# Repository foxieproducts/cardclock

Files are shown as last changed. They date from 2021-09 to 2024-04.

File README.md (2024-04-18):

# Check out the new [Foxie CardClock 2.0](https://github.com/foxieproducts/cardclock2)!

## Foxie CardClock 1.0

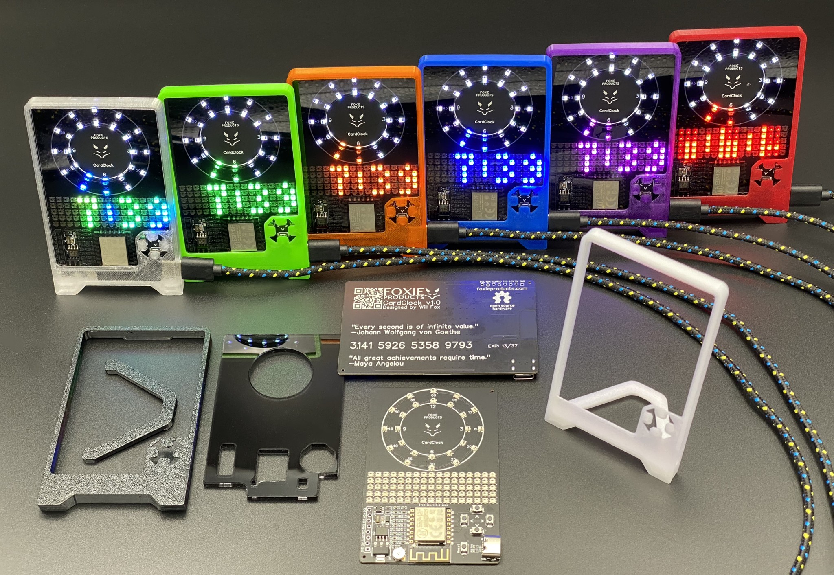
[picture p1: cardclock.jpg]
Foxie CardClock


### A smart, colorful, credit card sized clock

This is the Foxie CardClock, a certified Open Hardware ([OSHW US002055](https://certification.oshwa.org/us002055.html)), ESP8266-powered, WiFi-enabled, RTC-havin', super-capacitor havin', analog+digital, LED-laden, clock. The firmware is also able to self-update from the web, so improvements to this firmware can make their way to everyone's clocks.

There are 2 rings of 12 LEDs at the top of the PCB, which are used to display Hours, Minutes and Seconds. The Minutes and Seconds display with a 5 minute/second resolution.

Enter the 17x5 LED matrix, including a library that has functions for drawing characters, scrolling, and more. All A-Z, 0-9 and most symbols are supported (see [characters.hpp](firmware/src/characters.hpp)). Easy-to-read source code. 

There are also 4 buttons for up/down/left/right navigation, and finally a reset button for the ESP8266 programming. Hold the **down** button, then press reset to enter UART **down**load mode. Too cool for serial programming? The CardClock firmware also supports ArduinoOTA and most firmware development can be done wirelessly, as long as you don't make the firmware unbootable... if you do, grab your USB-to-serial adapter and reprogram it easily. 

There is a light sensor using the ESP8266's single analog input, providing for a smooth experience in brighter and darker environments. Minimum and maximum brightness are also easily adjustable directly on the clock using the menu system.

The CardClock syncs NTP time once a minute from the WiFi connection. It also keeps track of time using the onboard RTC. Unplug your clock? No problem, the time isn't lost because the built-in super-capacitor will keep the RTC powered for over 2 days. The moment you plug it back in, the time is still there, and if on WiFi, will be NTP sync'd moments later. It's the little things, right?

You can even 3d-print your own [case](case/) easily with nearly any 3d printer or easily modify it, with the included .step file. 

The [PCB](pcb/) was designed with EasyEDA.

## Easy to hack

The CardClock is powered by an Ai-Thinker ESP-12F, one of several modules based on the Espressif ESP8266. The ESP-12F is the same chip as in the NodeMCU and Wemos D1 products... could you get a python version of the CardClock firmware running? Might be a fun project!

The source code is written in object-oriented C++, built using PlatformIO inside VS Code. It has ArduinoOTA support (DEVL mode must be enabled in the clock's menu), along with a safe mode (hold the **left** button on boot) just in case you manage to brick the firmware somewhere after the initialization. Although, I highly recommend having a USB to Serial cable (such as a CP2102 MICRO USB to UART TTL Module) around, just in case.

The firmware uses several open-source libraries, including [ESPAsyncWiFiManager](https://github.com/alanswx/ESPAsyncWiFiManager]), [Rtc_Pcf8563](https://github.com/elpaso/Rtc_Pcf8563), [Adafruit's NeoPixel library](https://github.com/adafruit/Adafruit_NeoPixel) and all the amazing work from the [ESP8266 Arduino core](https://github.com/esp8266/Arduino) team.

# [Get your own](https://www.foxieproducts.com/)

Order your own at [foxieproducts.com/products/cardclock](https://www.foxieproducts.com/products/cardclock) or at the [Foxie Products store on Tindie](https://www.tindie.com/products/foxieproducts/foxie-cardclock/).

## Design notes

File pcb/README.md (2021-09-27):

# Printed Circuit Board

The CardClock PCB was designed with [EasyEDA](https://easyeda.com). The top layer has a copper pour for the GND net, while the bottom has two: a 3.3v area under the primary component area and a 5v area everywhere else. 
There is also a keep-out area underneath the ESP-12F antenna area.

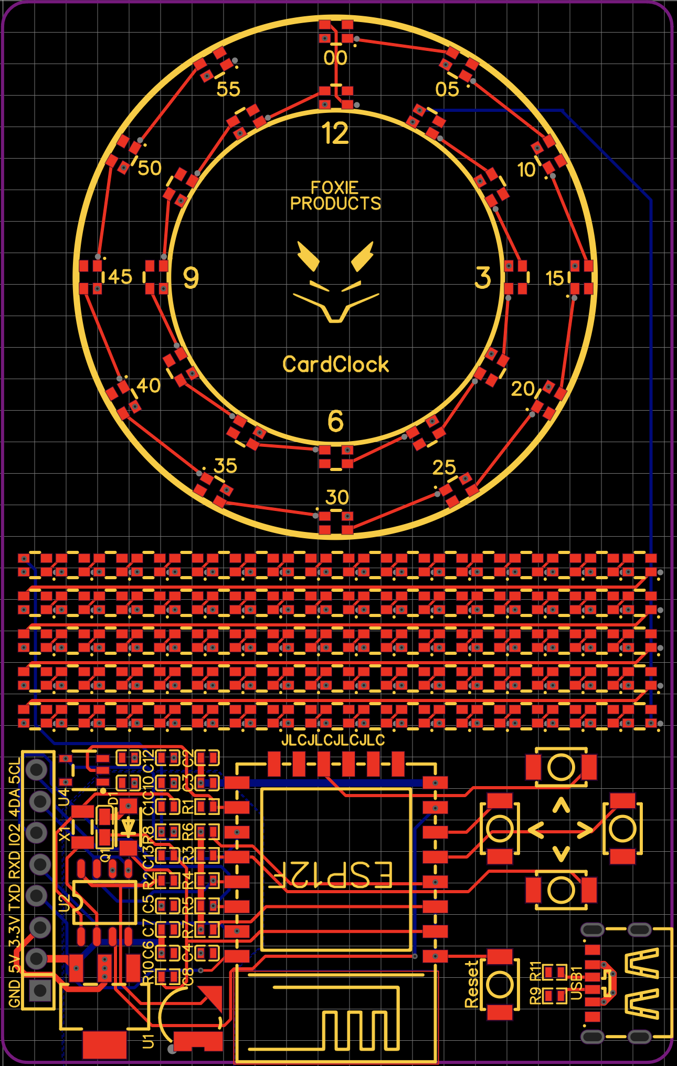
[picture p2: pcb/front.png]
Front
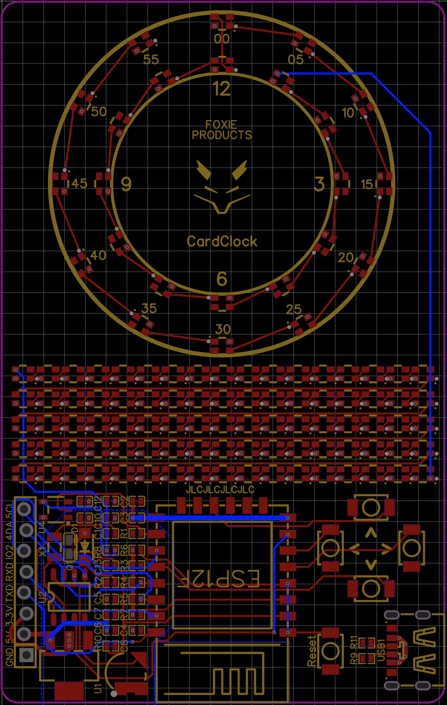
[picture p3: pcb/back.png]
Back
 

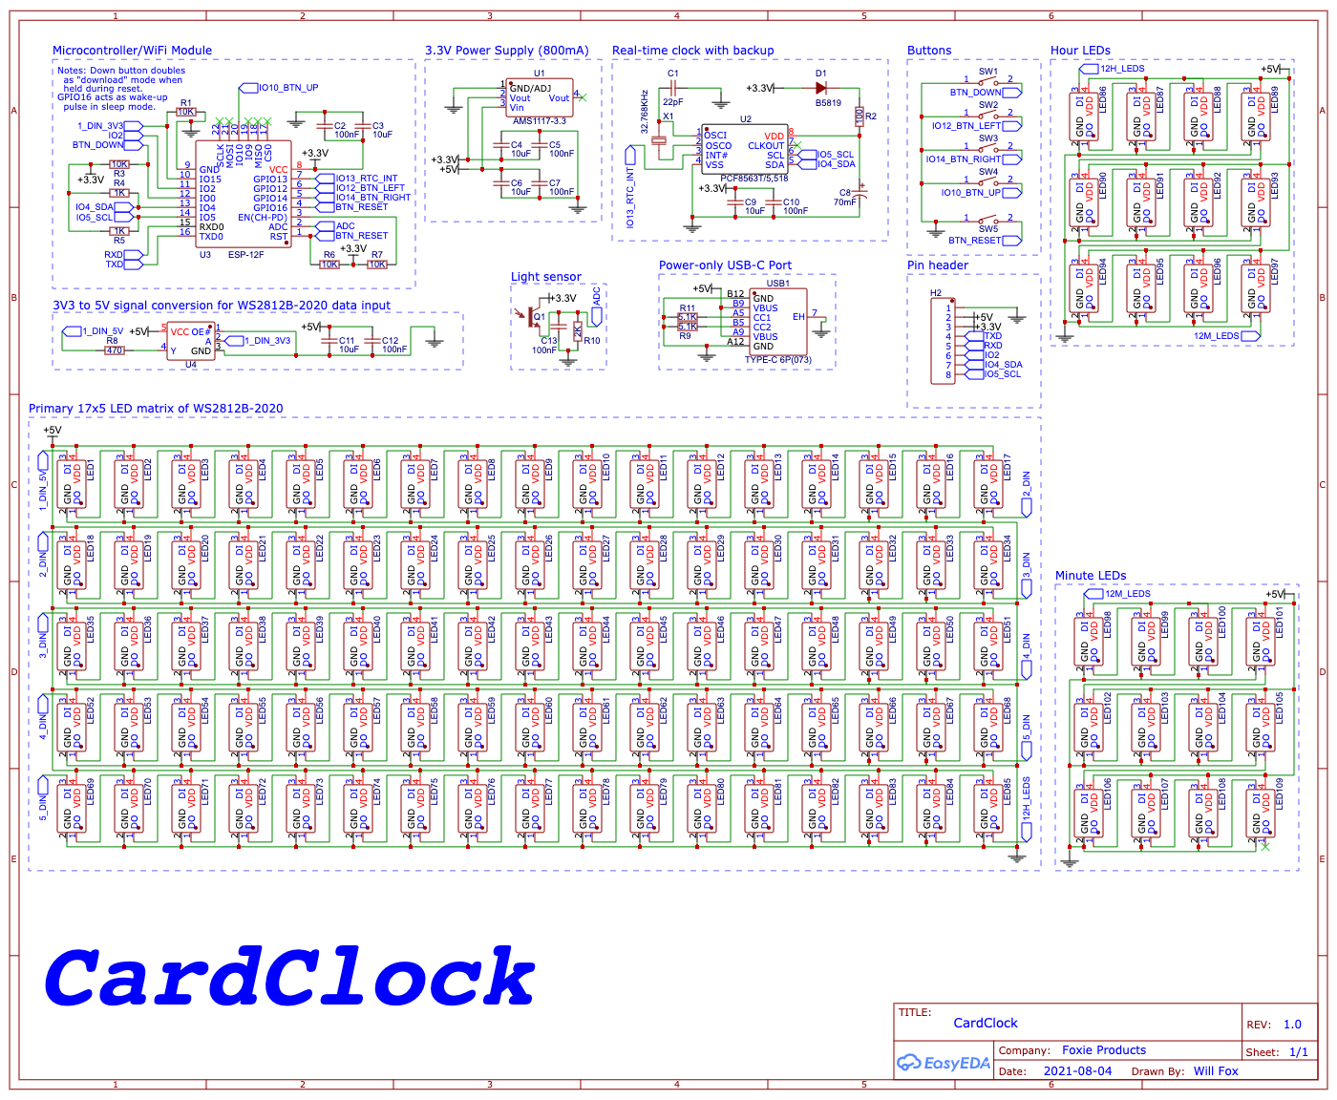
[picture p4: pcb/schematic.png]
Schematic


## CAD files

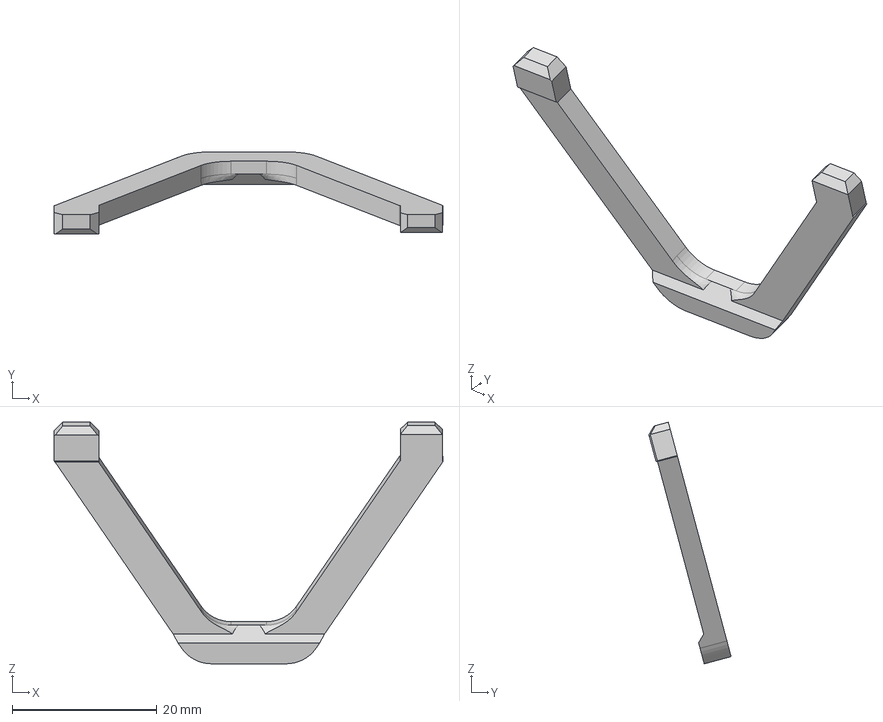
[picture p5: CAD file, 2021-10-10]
case/stand.step
53.7 x 11.4 x 33.4 mm

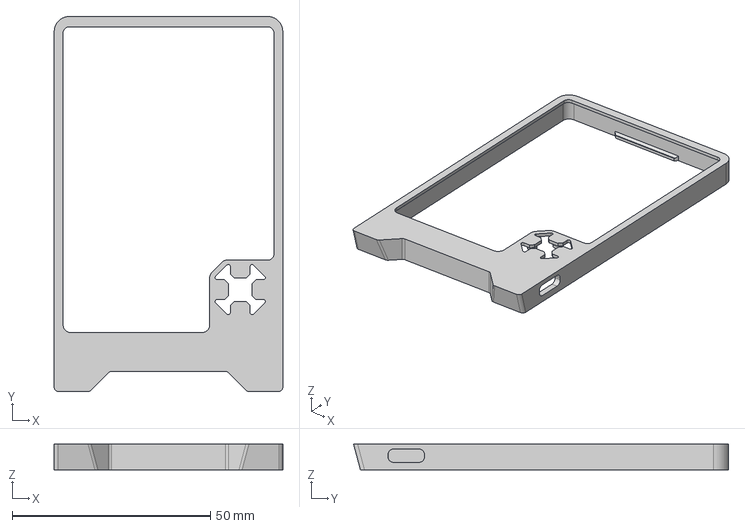
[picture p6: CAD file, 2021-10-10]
case/case.step
57.6 x 94.5 x 6.50 mm

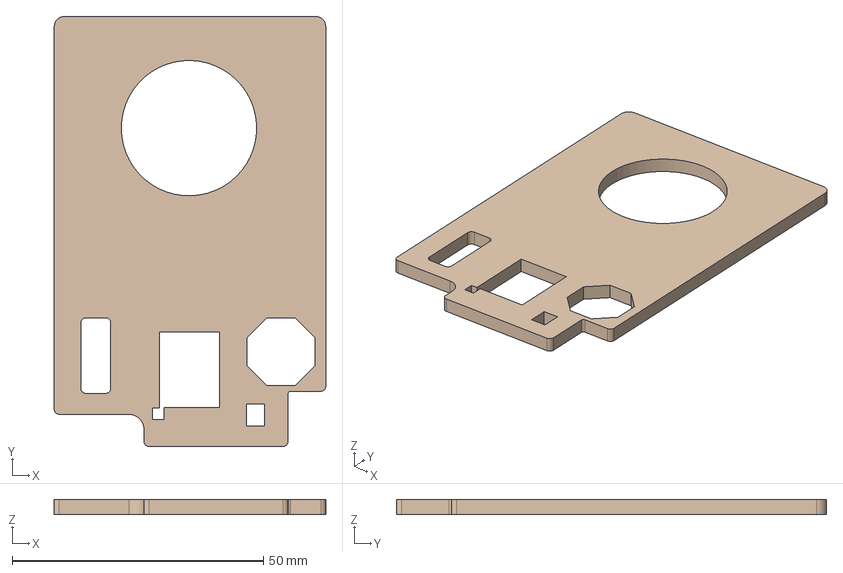
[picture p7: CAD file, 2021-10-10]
case/acrylic.step
54.0 x 85.5 x 3.00 mm

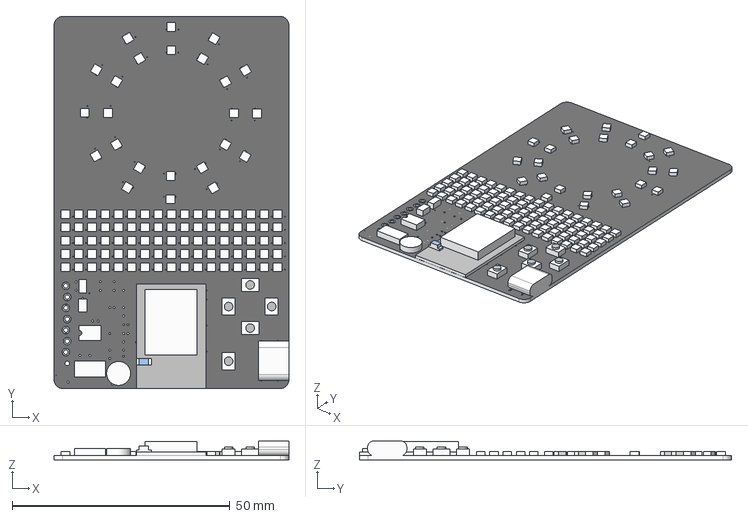
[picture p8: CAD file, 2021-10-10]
case/pcb.step
54.0 x 85.5 x 4.35 mm

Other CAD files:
case/case.3mf
case/stand.3mf

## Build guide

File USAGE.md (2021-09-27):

## CardClock Usage
---
[Set time]   <->   [Clock]   <->   [Configuration]

The CardClock starts up on the Clock screen.

Press **left** button to move from Clock to **set time**.
Press **right** button to move from Clock to **configure settings**.

Note: It is normal for the area by the Open Hardware gear on the back of the clock to be slightly warm.

## Changing the look on the Clock screen
---
Press the **up** button repeatedly to change the color at any time. A color wheel palette will be shown for a few moments. **Hold** down the **up** button to change colors more quickly.

Press the **down** button to change the **display mode**. There are several, and the list will loop back to the beginning once the end is reached.
Normal, Shimmer, Rainbow, Marquee, Marquee Rainbow, Binary, and Binary Shimmer 

## Setting the time
---
Press **left** button to move from Clock to **set time**.

Press left/right to switch between setting the hour, minute, or second.
Press up/down to increase or decrease the value. Hold the button down to move toward a value more quickly.
To exit, either wait 5 seconds or move to the seconds value and press the right button to move back to the Clock screen.

## Configuring settings
---
Press **right** button to move from Clock to **configure settings**.

Press the up/down buttons to move through the list of settings. The ring LEDs will display the position in the list.
Press the right button to select a setting, then press the up/down buttons to change the value.
To exit, either wait 5 seconds or press the left button to move back to the Clock screen.

MINB - MINimum Brightness - A setting below 8 will lose quite a bit of color variation

MAXB - MAXimum Brightness 

CLKB - CLocK Background - If enabled, the analog clock LEDs will be on

WLED - Wireless status LED - if enabled, an LED between the : separator will give status about whether the CardClock WiFi is connecting (heartbeat blink) or connected (solid)

24HR - 24 HouR - if enabled, hours are shown from 00:00-23:00 instead of 12:00-12:00

UTC - Universal Time Code offset - changes the time received from the Internet (UTC 0) to your local time zone. PDT = -7, MDT = -6, CDT = -5, EDT = -4, etc. 

WIFI - Configuring WiFi sets up SSID "Foxie_WiFiSetup" - connect from your phone, then you can set the CardClock to connect to your home WiFi for automatic NTP time synchronization.

INFO - Shows several bits of INFOrmation about the running state of the clock, including IP address (on WiFi)

VER - Shows the current VERsion of firmware

DEVL - DEVeLoper mode, enables AndroidOTA firmware updates over WiFi

UPDT - UPDaTe checks the current version of firmware from foxieproducts.com and prompts to confirm.

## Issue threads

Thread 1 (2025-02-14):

Compile errors

dunk8888, 2025-02-14:
Hi what boards version did you use for the ESP8266 also what was the rtc library version. Also Ide version ive tryed loads of different combos they  all gave different errors

foxieproducts, 2025-02-14:
Hi, I'm sorry you're having trouble building the firmware. Can you please attach the output errors you've seen?

dunk8888, 2025-02-16:
Hi its compiled now but getting bootloop error

rf cal sector: 1020
freq trace enable 0
rf[112] : 0a

foxieproducts, 2025-02-16:
I've never encountered that issue. Can you give some more details as to how you're loading the firmware and what you had to change to get it to compile?

dunk8888, 2025-02-18:
Well to start with i was trying to use Arduino ide as ive no experience with PlatformIO so tryed sorting the firmware out to run in Arduino ide, i failed with that and thought ive got to vive PlatformIO a go, turns out its quite easy to get grips with, so i grabes this firmware again nice and fresh and used PlatformIO, first i tryed uploading through serial but produced the rf error above, having googled about i read its ota firmware so i got to using the ota feature and flashed ok but still rf issue, i am using an R1 mini at the minute ile get an esp12f and try that, i did change the board to d1 mini in the Platformio. ini ive changed one button pin wich may of conflicted with things, so thats where ime at, ime gona order the proper esp its probably the d1 mini.

foxieproducts, 2025-02-18:
I appreciate the feedback and I'm sorry you're having trouble getting it going on your hardware.

I don't have any more original CardClocks (this repo, where the CC is vertical), but I did a new CardClock 2.0 (https://github.com/foxieproducts/cardclock2) last year, which you can also see at http://foxieclock.com. I still have a few available of my 2.0 designs.

dunk8888, 2025-02-26:
Hi no worries, i have seen the CC2 and FC2 shipping is same price as clock
to my home, but its ok ive made gerbers of the CC1 an its been fabed, ile
enjoy soldering all them leds on 😁 its debugging code the bugs me Good way
of learning.
So ile build the clock then see if i can get the firmware going on it,
whats the best way to upload, ota or esptools, i think my problem is the d1
mini i used ive seen loads online with same issue same board, its just bad
parts or config of the cheap boards

On Tue, 18 Feb 2025, 8:48 pm foxieproducts, ***@***.***>
wrote:

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

dunk8888, 2025-03-01:
Do you have a binery ide could flash to rule out code isue, ime having same results with an esp12f

foxieproducts, 2025-03-01:
I don't have a binary to provide, unfortunately. Good luck with your project. I'm going to close this ticket and I wish you luck.

Closed 2025-03-01.

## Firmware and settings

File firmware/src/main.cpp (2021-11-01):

#include <Arduino.h>
#include <ESP8266WiFi.h>
#include <LittleFS.h>
#include <user_interface.h>  // for ESP-specific API calls
#include <memory>            // for std::shared_ptr

// you might be asking yourself -- why is all the code in header files?
// answer: in a relatively small project like this, the separation of .hpp/.cpp
// files adds an unnecessarily cumbersome layer to rapid iteration

#include "clock.hpp"
#include "config_menu.hpp"
#include "display.hpp"
#include "foxie_ntp.hpp"
#include "foxie_wifi.hpp"
#include "option.hpp"
#include "settings.hpp"
#include "time_menu.hpp"
#include "web_update.hpp"

void CheckButtonsOnBoot(Settings& settings, Display& display, FoxieWiFi& wifi);

void setup() {
    using namespace std;
    auto settings = make_shared<Settings>();
    auto display = make_shared<Display>(*settings);
    auto wifi = make_shared<FoxieWiFi>(*settings, *display);
    auto updater = make_shared<WebUpdate>(*settings, *display);

    CheckButtonsOnBoot(*settings, *display, *wifi);

    auto rtc = make_shared<Rtc>(*settings);
    auto ntp = make_shared<FoxieNTP>(*settings, *rtc);
    auto menuMgr = make_shared<MenuManager>(*display, *settings);

    menuMgr->Add(make_shared<TimeMenu>(*display, *rtc, *settings));  // menu 0
    menuMgr->Add(make_shared<Clock>(*display, *rtc, *settings));     // menu 1

    // all config menu options are below
    auto configMenu = make_shared<ConfigMenu>(*display, *settings);  // menu 2
    configMenu->AddRangeSetting(F("MINB"), MIN_BRIGHTNESS, MAX_BRIGHTNESS);
    configMenu->AddRangeSetting(F("MAXB"), MIN_BRIGHTNESS, MAX_BRIGHTNESS);
    configMenu->AddTextSetting(F("CLKB"), {F("OFF"), F("ON")});
    configMenu->AddTextSetting(F("WLED"), {F("OFF"), F("ON")});
    configMenu->AddTextSetting(F("24HR"), {"OFF", "ON"});
    configMenu->AddRangeSetting(F("UTC"), -12, 12,
                                [&]() { ntp->UpdateRTCTime(); });
    configMenu->AddTextSetting(F("WIFI"), {"OFF", "ON", "CFG"});
    configMenu->AddRunFuncSetting(F("INFO"), [&]() {
        String info;
        info += F("IP:");
        info +=
            WiFi.isConnected() ? WiFi.localIP().toString() : F("NOT CONNECTED");
        info += F(" FH:") + String(ESP.getFreeHeap());
        info += F(" FCS:") + String(ESP.getFreeContStack());
        info += F(" UPT:") + String(millis() / 1000 / 60);

        display->DrawTextScrolling(info, GREEN);
    });
    configMenu->AddRunFuncSetting(F("VER"), [&]() {
        display->DrawTextScrolling(F("FC/OS v") + String(FW_VERSION) +
                                       F(" and may the schwartz be with you!"),
                                   PURPLE);
    });
    configMenu->AddTextSetting(F("DEVL"), {F("OFF"), F("ON")});
    configMenu->AddRunFuncSetting(F("UPDT"), [&]() { updater->Download(); });
    menuMgr->Add(configMenu);

    menuMgr->SetDefaultAndActivateMenu(1);  // clock menu

    // use a while loop instead of loop() ... I just hate globals, OK?
    while (true) {
        rtc->Update();
        ntp->Update();
        menuMgr->Update();
        wifi->Update();
        display->Update();

        yield();  // allow the ESP's system/WiFi code a chance to run
    }
}

void CheckButtonsOnBoot(Settings& settings, Display& display, FoxieWiFi& wifi) {
    pinMode(PIN_BTN_UP, INPUT_PULLUP);
    pinMode(PIN_BTN_DOWN, INPUT);
    pinMode(PIN_BTN_LEFT, INPUT_PULLUP);
    pinMode(PIN_BTN_RIGHT, INPUT_PULLUP);

    // if left button is held on boot, go into safe mode. this still allows
    // ArduinoOTA to function and the firmware can be updated using espota
    // just in case you accidentally put the board into a reboot loop that
    // doesn't involve any of the code this "safe" mode depends on...
    if (Button::AreAnyButtonsPressed() == PIN_BTN_LEFT) {
        display.DrawTextCentered(F("SAFE"), ORANGE);
        settings[F("DEVL")] == F("ON");
        while (true) {
            wifi.Update();
            display.Update();

            yield();  // allow the ESP's system/WiFi code a chance to run
        }
    }

    // if UP button is held on boot, clear settings.
    if (Button::AreAnyButtonsPressed() == PIN_BTN_UP) {
        display.SetBrightness(20);
        display.DrawText(0, F("CLR?"), ORANGE);
        display.DrawChar(14, CHAR_RIGHT_ARROW, GREEN);
        display.Show();

        if (Button::WaitForButtonPress() == PIN_BTN_RIGHT) {
            display.DrawTextScrolling(F("SETTINGS CLEARED"), PURPLE);
            settings.clear();
            settings.Save();
            ESP.eraseConfig();
            Rtc_Pcf8563 rtc;
            rtc.zeroClock();
            Button::WaitForNoButtons();
            ESP.restart();
        }
    }
}

void loop() {}

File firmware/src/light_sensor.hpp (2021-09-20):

#pragma once
#include <Arduino.h>         // for map()
#include <stdint.h>          // for uint16_t and others
#include <user_interface.h>  // for ESP-specific API calls

#include "elapsed_time.hpp"

/**
 * This class solves two problems:
 * 1. It uses the ESP API to read multiple samples from the ADC.
 *    The main reason this is used instead of analogRead() is because
 *    analogRead() is unstable on the ESP8266 and crashes often (???)
 * 2. It provides averaging so that light changes happen gradually,
 *    which helps eliminate flicker
 * */
class LightSensor {
  public:
    enum {
        ADC_SAMPLES = 8,
        ADC_CLOCK_DIVIDER = 8,
        MIN_SENSOR_VAL = 10,  // affected by side lighting from the display LEDs
                              // below this level
        MAX_SENSOR_VAL = 100,
        JITTER = 3,

        HISTORY_SIZE = 80,
    };

  private:
    uint16_t* m_samples{nullptr};
    uint16_t* m_history{nullptr};
    size_t m_historyPos{0};

    ElapsedTime m_timeSinceBrightnessSet;
    float m_curBrightness{0.0f};

  public:
    LightSensor() {
        m_samples = (uint16_t*)zalloc(ADC_SAMPLES * sizeof(uint16_t));
        m_history = (uint16_t*)zalloc(HISTORY_SIZE * sizeof(uint16_t));

        for (size_t i = 0; i < HISTORY_SIZE; ++i) {
            m_history[i] = GetCurrentADCValue();
        }
        m_curBrightness = GetHistoryMean();
    }

    size_t Get() {
        m_history[m_historyPos] = GetCurrentADCValue();
        if (m_historyPos++ == HISTORY_SIZE) {
            m_historyPos = 0;
        }

        uint16_t mean = GetHistoryMean();
        if (m_timeSinceBrightnessSet.Ms() > 40) {
            if (mean < m_curBrightness - JITTER ||
                mean > m_curBrightness + JITTER) {
                // move quickly toward current brightness
                m_curBrightness = (mean + m_curBrightness) / 2;
            } else {
                // move slowly toward current brightness
                if (m_curBrightness >= MAX_SENSOR_VAL - JITTER) {
                    // increase the mean slightly so we can get to
                    // MAX_SENSOR_VAL
                    mean++;
                }
                const float value = (99.0f * m_curBrightness) + mean;
                m_curBrightness = value / 100.0f;
            }
            m_timeSinceBrightnessSet.Reset();
        }

        return m_curBrightness;
    }

  private:
    size_t GetHistoryMean() {
        size_t mean = 0;
        for (size_t i = 0; i < HISTORY_SIZE; i++) {
            mean += m_history[i];
        }

        return mean / HISTORY_SIZE;
    }

    // get a smoothed, bounded value from the sensor
    size_t GetCurrentADCValue() {
        system_soft_wdt_stop();
        ets_intr_lock();
        noInterrupts();

        system_adc_read_fast(m_samples, ADC_SAMPLES, ADC_CLOCK_DIVIDER);

        interrupts();
        ets_intr_unlock();
        system_soft_wdt_restart();

        size_t mean = 0;
        for (size_t i = 0; i < ADC_SAMPLES; i++) {
            mean += m_samples[i];
        }
        return constrain((mean / ADC_SAMPLES), MIN_SENSOR_VAL, MAX_SENSOR_VAL);
    }
};

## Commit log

2021-09-08 Improved light sensor class further, still working on it
2021-09-08 Now displays current second on the minute LEDs
2021-09-12 Default button repeat to true
2021-09-13 Fix hw_test minor breaks due to recent changes in Display and Button
    [hw_test.cpp]
2021-09-13 Relocate Pins_e to button.hpp
2021-09-13 More light sensor tweaks. Won't be the last.
    [light_sensor.hpp]
2021-09-15 Build fixes for hw_test and main
    [main.cpp]
2021-09-15 ArduinoOTA updates now working
2021-09-15 Another improvement to hopefully fix the clock interrupts correctly on boot
2021-09-15 Move WiFi status LED display to ClockMenu
2021-09-15 Change WiFi status LED to white
2021-09-16 Pressing a button while scrolling a message increases speed
2021-09-16 Make button repeats faster
2021-09-16 Switch to using MINB and MAXB settings for brightness
2021-09-16 Add option to disable wireless status LED
2021-09-17 Switch display characters to be in code instead of RAM, saves about 4K of RAM which is needed for the web update code.
2021-09-17 Show % during ArduinoOTA updates
2021-09-17 Switching to inline flash strings to save heap
2021-09-17 Interrupt guard call to updating pixels, still experiencing a rare random reboot
    [display.hpp]
2021-09-17 Switch to std::make_shared
2021-09-17 More light sensor tweaks
2021-09-18 Reworked light sensor code, behaves far better
    [light_sensor.hpp]
2021-09-18 Remove static Buttons::Update method
2021-09-18 OTA/Web Update improvements, back button now cancels update
2021-09-18 RTC Millis() backup method should include 1000
2021-09-18 Switch to uint32_t for colors
2021-09-19 Fix DrawTextScrolling so it doesn't ignore brightness
    [button.hpp, display.hpp]
2021-09-19 Fix bug with message color coming out of rainbow mode
    [clock.hpp]
2021-09-19 Speed up vertical scrolling and shorten button debounce time
    [button.hpp, display.hpp]
2021-09-20 Renaming, cleanup and bug fixes, oh myyy
    [button.hpp, clock.hpp, display.hpp]
2021-09-20 Restore the accidentally removed code that disables blue LED
2021-09-20 Improved handling of ring LEDs at low display brightness levels
2021-09-20 Ensure that RTC::Millis() does not return more than 1000
2021-09-20 Fix below-default brightness adjustment
    [clock.hpp]
2021-09-20 Pressing left/right buttons should also reset the timeout
2021-09-20 Improve the button-related code outside the Menus a little bit
2021-09-21 Fix bug with wifi status LED blinking when settings are cleared and WiFi isn't enabled
    [clock.hpp]
2021-09-21 Adding case resources
    [case.3mf, case.step, stand.3mf]
2021-09-22 Adding EasyEDA pcb and schematic
2021-09-25 RangeListOption can change the setting on each button press. This is useful for the MINB and MAXB settings, because they're constantly being used as the display updates. So now, turning the brightnes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
2021-09-26 Reset clock to zero when settings are cleared (holding UP button on boot)
    [main.cpp]
2021-09-26 Adding images of schematic, back and front of PCB
2021-09-26 Re-export schematic png
2021-10-10 Include .step files for all parts
    [acrylic.step, case.step, pcb.step]
2021-10-10 Separate case and stand step files
    [case.step, stand.step]
2021-12-16 Correct issue with resetting Millis() too often
2021-12-16 Improve up/down button functionality for color/animation selection
2021-12-29 Fix analog hour display when 24HR mode is enabled
    [clock.hpp]
